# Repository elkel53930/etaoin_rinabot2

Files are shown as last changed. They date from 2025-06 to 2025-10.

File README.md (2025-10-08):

# 璃奈ちゃんbot TYPE2

このリポジトリは、同人誌「璃奈ちゃんを作ろう！TYPE2」の参考資料を公開するものです。

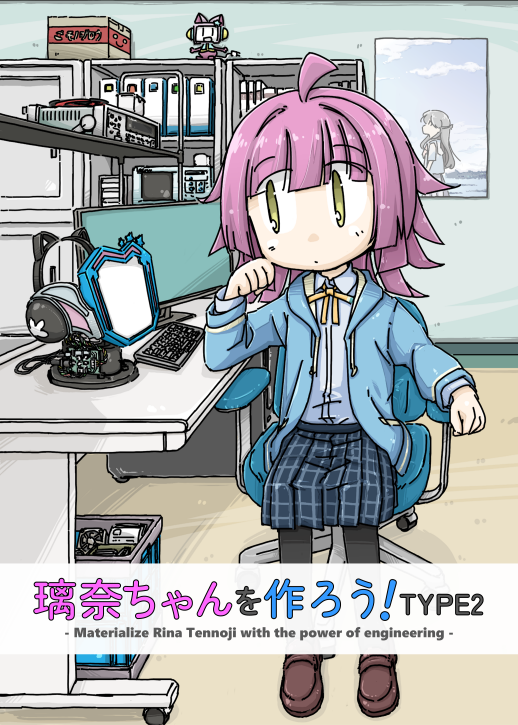
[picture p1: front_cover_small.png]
"璃奈ちゃんを作ろう！TYPE2 表紙画像"


## ディレクトリ構成

```
etaoin_rinabot2
├── app : 主にPythonスクリプト
│   ├── board : 璃奈ちゃんboard
│   ├── drive : 璃奈ちゃんdrive
│   ├── etc : その他スクリプト
│   ├── frame : 璃奈ちゃんframe
│   ├── rinabot : 高レベルスクリプトやシナリオ実行スクリプト
│   ├── scenario : サンプルシナリオファイル
│   ├── slide : スライドショー機能
│   └── speech : 璃奈ちゃんspeech
├── elec : 各プリント基板のKiCadデータ
│   ├── board : 璃奈ちゃんboard制御基板
│   ├── hub : ハブ基板
│   ├── led_a : LEDのモジュール
│   └── motor_driver : 璃奈ちゃんdrive制御基板
└── fsw : ファームウェア
　   ├── board : 璃奈ちゃんboard
　   └── drive : 璃奈ちゃんdrive
```

## 3DCADデータ

3DCADデータは以下のURLで公開しています。
Google Chromeでは表示できないことがあるようです。
Microsoft Edgeで閲覧可能であることを確認しています。

https://a360.co/4q07Nhn

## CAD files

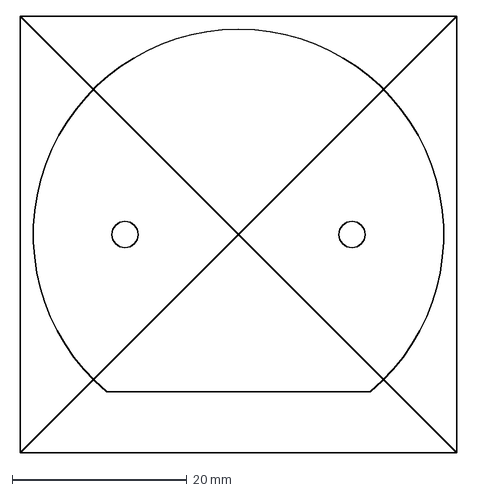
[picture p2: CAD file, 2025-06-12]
elec/motor_driver/outline.dxf
50.9 x 50.0 mm

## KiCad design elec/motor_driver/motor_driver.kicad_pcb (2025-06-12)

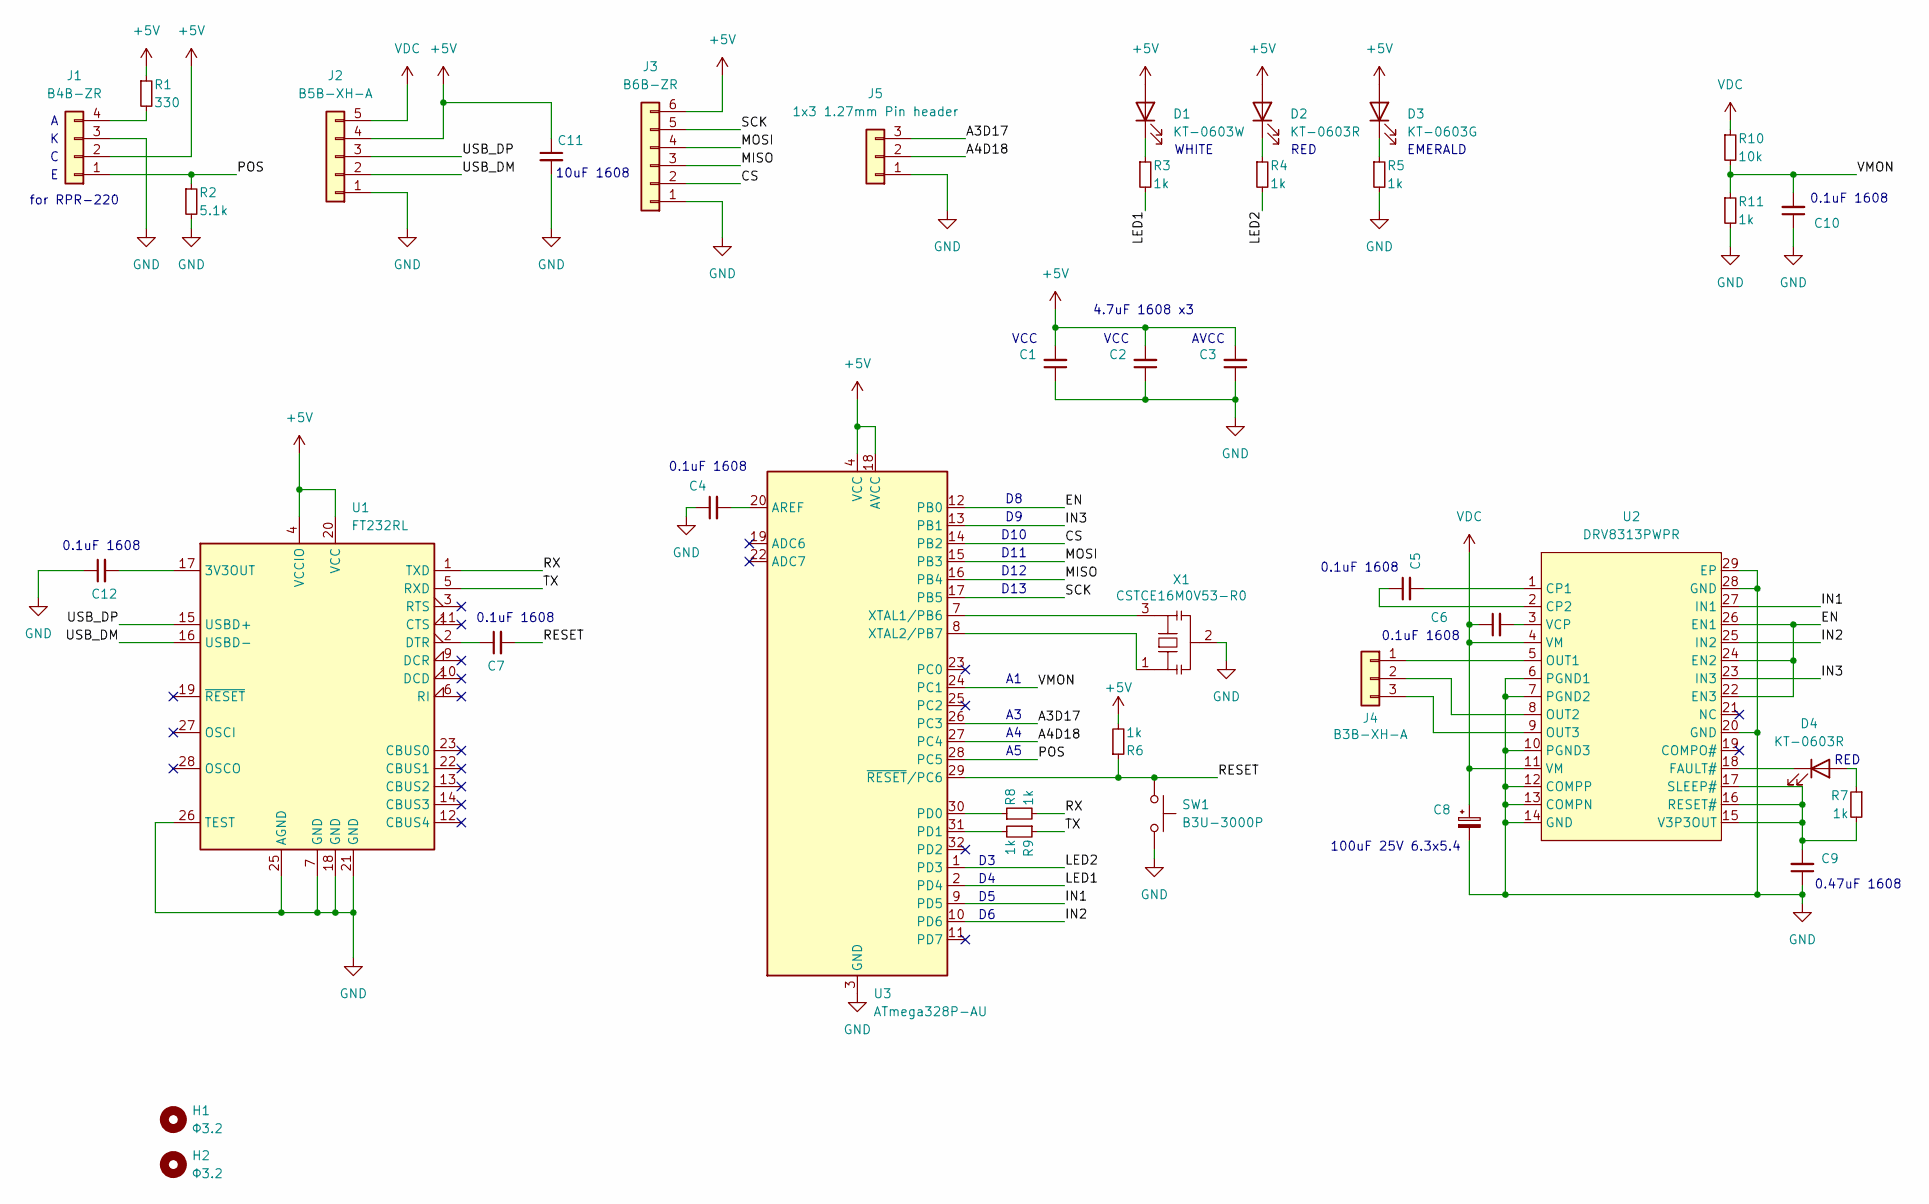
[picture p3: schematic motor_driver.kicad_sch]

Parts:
C1, C2, C3: CL10A475KO8NNNC; C_0603_1608Metric
C4, C5, C6, C7, C10, C12: CC0603KRX7R9BB104; C_0603_1608Metric
C8: RST100UF25V004; CP_Elec_6.3x5.4
C9: CL10B474KA8NNNC; C_0603_1608Metric
C11: CL10A106KP8NNNC; C_0603_1608Metric
D1: KT-0603W; LED_0603_1608Metric
D2, D4: KT-0603R; LED_0603_1608Metric
D3: KT-0603G; LED_0603_1608Metric
H1, H2: Φ3.2; MountingHole_3.2mm_M3
J1: B4B-ZR; JST_ZH_B4B-ZR_1x04_P1.50mm_Vertical
J2: B5B-XH-A; JST_XH_B5B-XH-A_1x05_P2.50mm_Vertical
J3: B6B-ZR; JST_ZH_B6B-ZR_1x06_P1.50mm_Vertical
J4: B3B-XH-A; JST_XH_B3B-XH-A_1x03_P2.50mm_Vertical
J5: 1x3 1.27mm Pin header; PinHeader_1x03_P1.27mm_Vertical
R1: 330; R_0603_1608Metric
R2: 5.1k; R_0603_1608Metric
R3, R4, R5, R6, R7, R8, R9, R11: 1k; R_0603_1608Metric
R10: 10k; R_0603_1608Metric
SW1: B3U-3000P; SW_SPST_B3U-3000P-B
U1: FT232RL; SSOP-28_5.3x10.2mm_P0.65mm
U2: DRV8313PWPR; HTSSOP-28-1EP_4.4x9.7mm_P0.65mm_EP2.75x6.2mm_ThermalVias
U3: ATmega328P-AU; TQFP-32_7x7mm_P0.8mm
X1: CSTCE16M0V53-R0; CSTCE

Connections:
+5V: C1.2, C2.2, C3.2, C11.1, D1.2 (A), D2.2 (A), D3.2 (A), J1.2, J2.4, J3.6, R1.1, R6.2, U1.4 (VCCIO), U1.20 (VCC), U3.4 (VCC), U3.6 (VCC), U3.18 (AVCC)
/A3D17: J5.3, U3.26 (PC3)
/A4D18: J5.2, U3.27 (PC4)
/CS: J3.2, U3.14 (PB2)
/EN: U2.22 (EN3), U2.24 (EN2), U2.26 (EN1), U3.12 (PB0)
/IN1: U2.27 (IN1), U3.9 (PD5)
/IN2: U2.25 (IN2), U3.10 (PD6)
/IN3: U2.23 (IN3), U3.13 (PB1)
/LED1: R3.2, U3.2 (PD4)
/LED2: R4.2, U3.1 (PD3)
/MISO: J3.3, U3.16 (PB4)
/MOSI: J3.4, U3.15 (PB3)
/POS: J1.1, R2.1, U3.28 (PC5)
/RESET: C7.2, R6.1, SW1.1, U3.29 (~RESET/PC6)
/RX: R8.2, U1.1 (TXD)
/SCK: J3.5, U3.17 (PB5)
/TX: R9.1, U1.5 (RXD)
/USB_DM: J2.2, U1.16 (USBD-)
/USB_DP: J2.3, U1.15 (USBD+)
/VMON: C10.2, R10.2, R11.1, U3.24 (PC1)
GND: C1.1, C2.1, C3.1, C4.1, C8.2, C9.1, C10.1, C11.2, C12.1, J1.3, J2.1, J3.1, J5.1, R2.2, R5.2, R11.2, SW1.2, U1.7 (GND), U1.18 (GND), U1.21 (GND), U1.25 (AGND), U1.26 (TEST), U2.6 (PGND1), U2.7 (PGND2), U2.10 (PGND3), U2.12 (COMPP), U2.13 (COMPN), U2.14 (GND), U2.20 (GND), U2.28 (GND), U2.29 (EP), U3.3 (GND), U3.5 (GND), U3.21 (GND), X1.2
unnamed: D1.1 (K), R3.1
unnamed: D2.1 (K), R4.1
unnamed: D3.1 (K), R5.1
unnamed: D4.2 (A), R7.1
unnamed: D4.1 (K), U2.18 (FAULT#)
unnamed: J1.4, R1.2
unnamed: J4.1, U2.5 (OUT1)
unnamed: J4.2, U2.8 (OUT2)
unnamed: J4.3, U2.9 (OUT3)
unnamed: C12.2, U1.17 (3V3OUT)
unnamed: C7.1, U1.2 (DTR)
unnamed: C5.2, U2.1 (CP1)
unnamed: C5.1, U2.2 (CP2)
unnamed: C9.2, R7.2, U2.15 (V3P3OUT), U2.16 (RESET#), U2.17 (SLEEP#)
unnamed: C6.2, U2.3 (VCP)
unnamed: C4.2, U3.20 (AREF)
unnamed: R8.1, U3.30 (PD0)
unnamed: R9.2, U3.31 (PD1)
unnamed: U3.7 (XTAL1/PB6), X1.3
unnamed: U3.8 (XTAL2/PB7), X1.1
VDC: C6.1, C8.1, J2.5, R10.1, U2.4 (VM), U2.11 (VM)

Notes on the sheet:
D12
VCC
RED
D10
EMERALD
0.1uF 1608
WHITE
100uF 25V 6.3x5.4
10uF 1608
AVCC
for RPR-220
0.47uF 1608
4.7uF 1608 x3
D13
D11

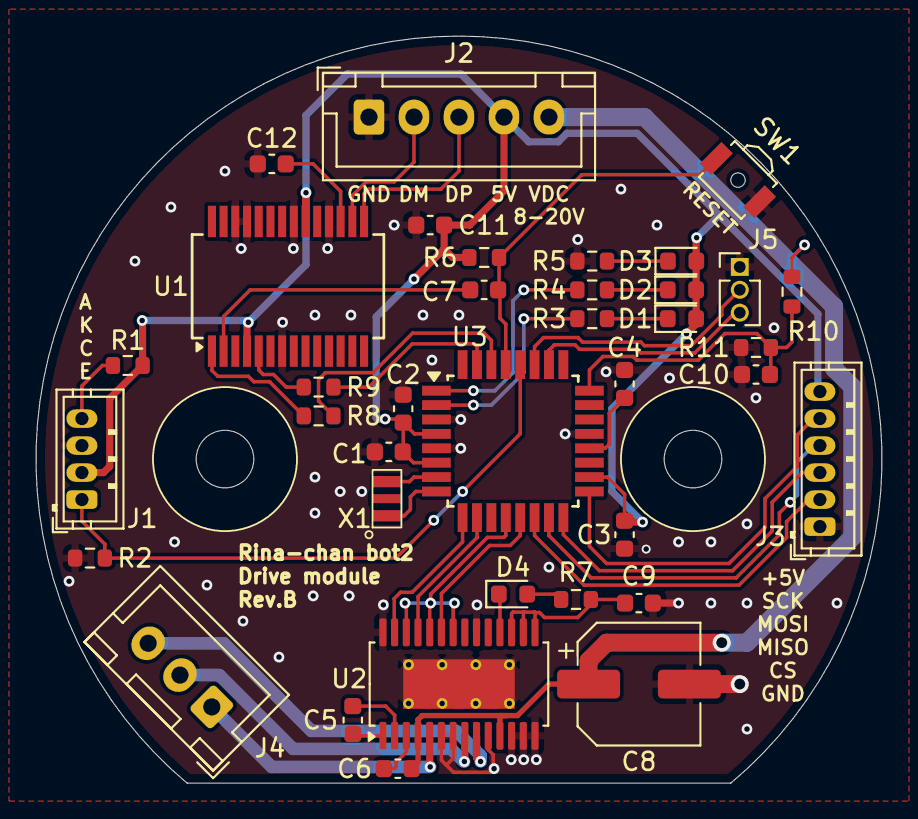
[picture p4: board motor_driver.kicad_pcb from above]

Board: 2 copper layers, 47.0 x 41.5 mm, 39 parts (0 on the bottom side), 42 nets.

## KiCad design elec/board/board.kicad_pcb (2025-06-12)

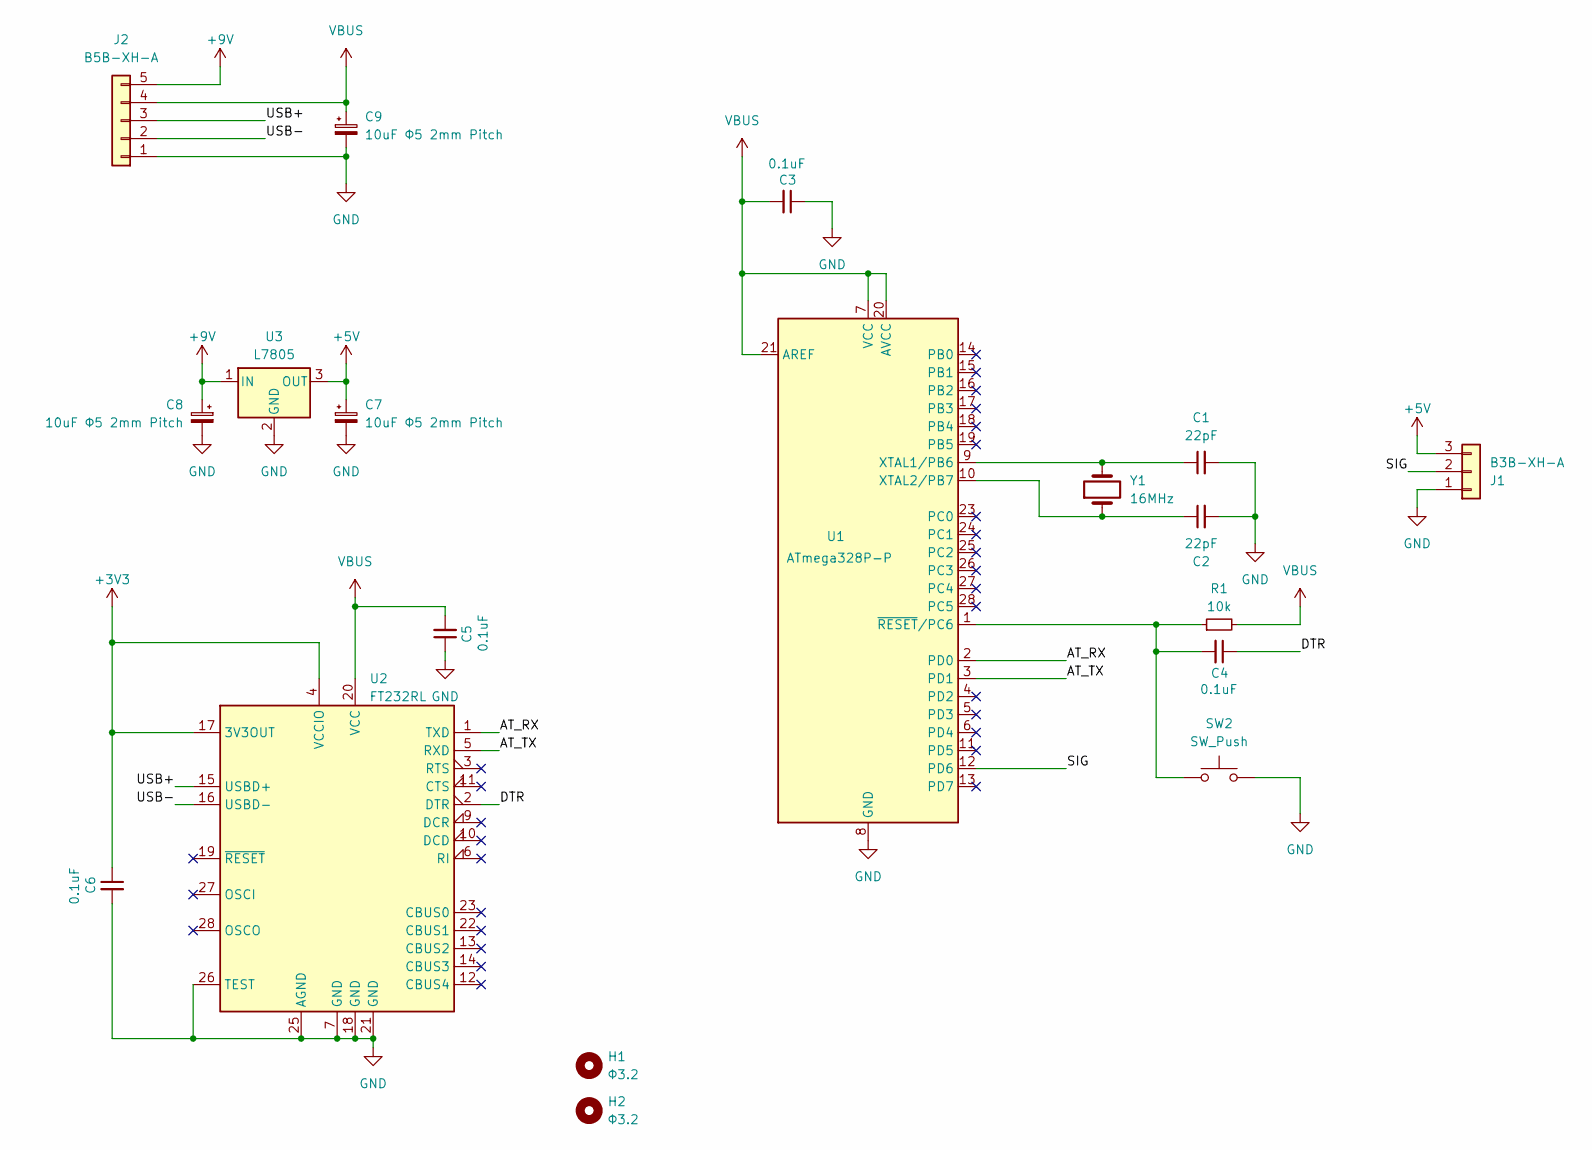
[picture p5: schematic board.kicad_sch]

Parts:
C1, C2: 22pF; C_Disc_D5.1mm_W3.2mm_P5.00mm
C3, C4, C5, C6: 0.1uF; C_Disc_D5.1mm_W3.2mm_P5.00mm
C7, C8, C9: 10uF Φ5 2mm Pitch; CP_Radial_D5.0mm_P2.00mm
H1, H2: Φ3.2; MountingHole_3.2mm_M3
J1: B3B-XH-A; JST_XH_B3B-XH-A_1x03_P2.50mm_Vertical
J2: B5B-XH-A; JST_XH_B5B-XH-A_1x05_P2.50mm_Vertical
R1: 10k; R_Axial_DIN0207_L6.3mm_D2.5mm_P7.62mm_Horizontal
SW2: SW_Push; SW_PUSH_6mm
U1: ATmega328P-P; DIP-28_W7.62mm
U2: FT232RL; SSOP-28_5.3x10.2mm_P0.65mm
U3: L7805; TO-220F-3_Vertical
Y1: 16MHz; Crystal_HC49-4H_Vertical

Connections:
+3V3: C6.1, U2.4 (VCCIO), U2.17 (3V3OUT)
+5V: C7.1, J1.3, U3.3 (OUT)
+9V: C8.1, J2.5, U3.1 (IN)
/AT_RX: U1.2 (PD0), U2.1 (TXD)
/AT_TX: U1.3 (PD1), U2.5 (RXD)
/DTR: C4.1, U2.2 (DTR)
/SIG: J1.2, U1.12 (PD6)
/USB+: J2.3, U2.15 (USBD+)
/USB-: J2.2, U2.16 (USBD-)
GND: C1.2, C2.2, C3.1, C5.1, C6.2, C7.2, C8.2, C9.2, J1.1, J2.1, SW2.2, U1.8 (GND), U1.22 (GND), U2.7 (GND), U2.18 (GND), U2.21 (GND), U2.25 (AGND), U2.26 (TEST), U3.2 (GND)
unnamed: C1.1, U1.9 (XTAL1/PB6), Y1.2
unnamed: C2.1, U1.10 (XTAL2/PB7), Y1.1
unnamed: C4.2, R1.1, SW2.1, U1.1 (~RESET/PC6)
VBUS: C3.2, C5.2, C9.1, J2.4, R1.2, U1.7 (VCC), U1.20 (AVCC), U1.21 (AREF), U2.20 (VCC)

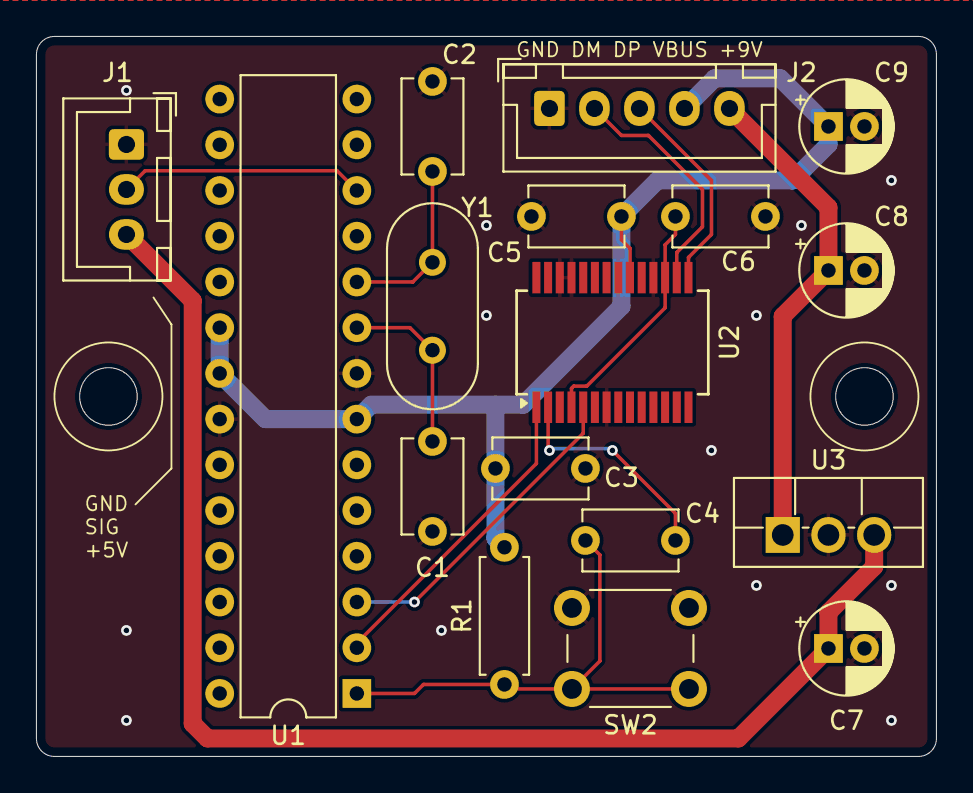
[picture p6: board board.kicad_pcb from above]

Board: 2 copper layers, 50.0 x 40.0 mm, 19 parts (0 on the bottom side), 14 nets.

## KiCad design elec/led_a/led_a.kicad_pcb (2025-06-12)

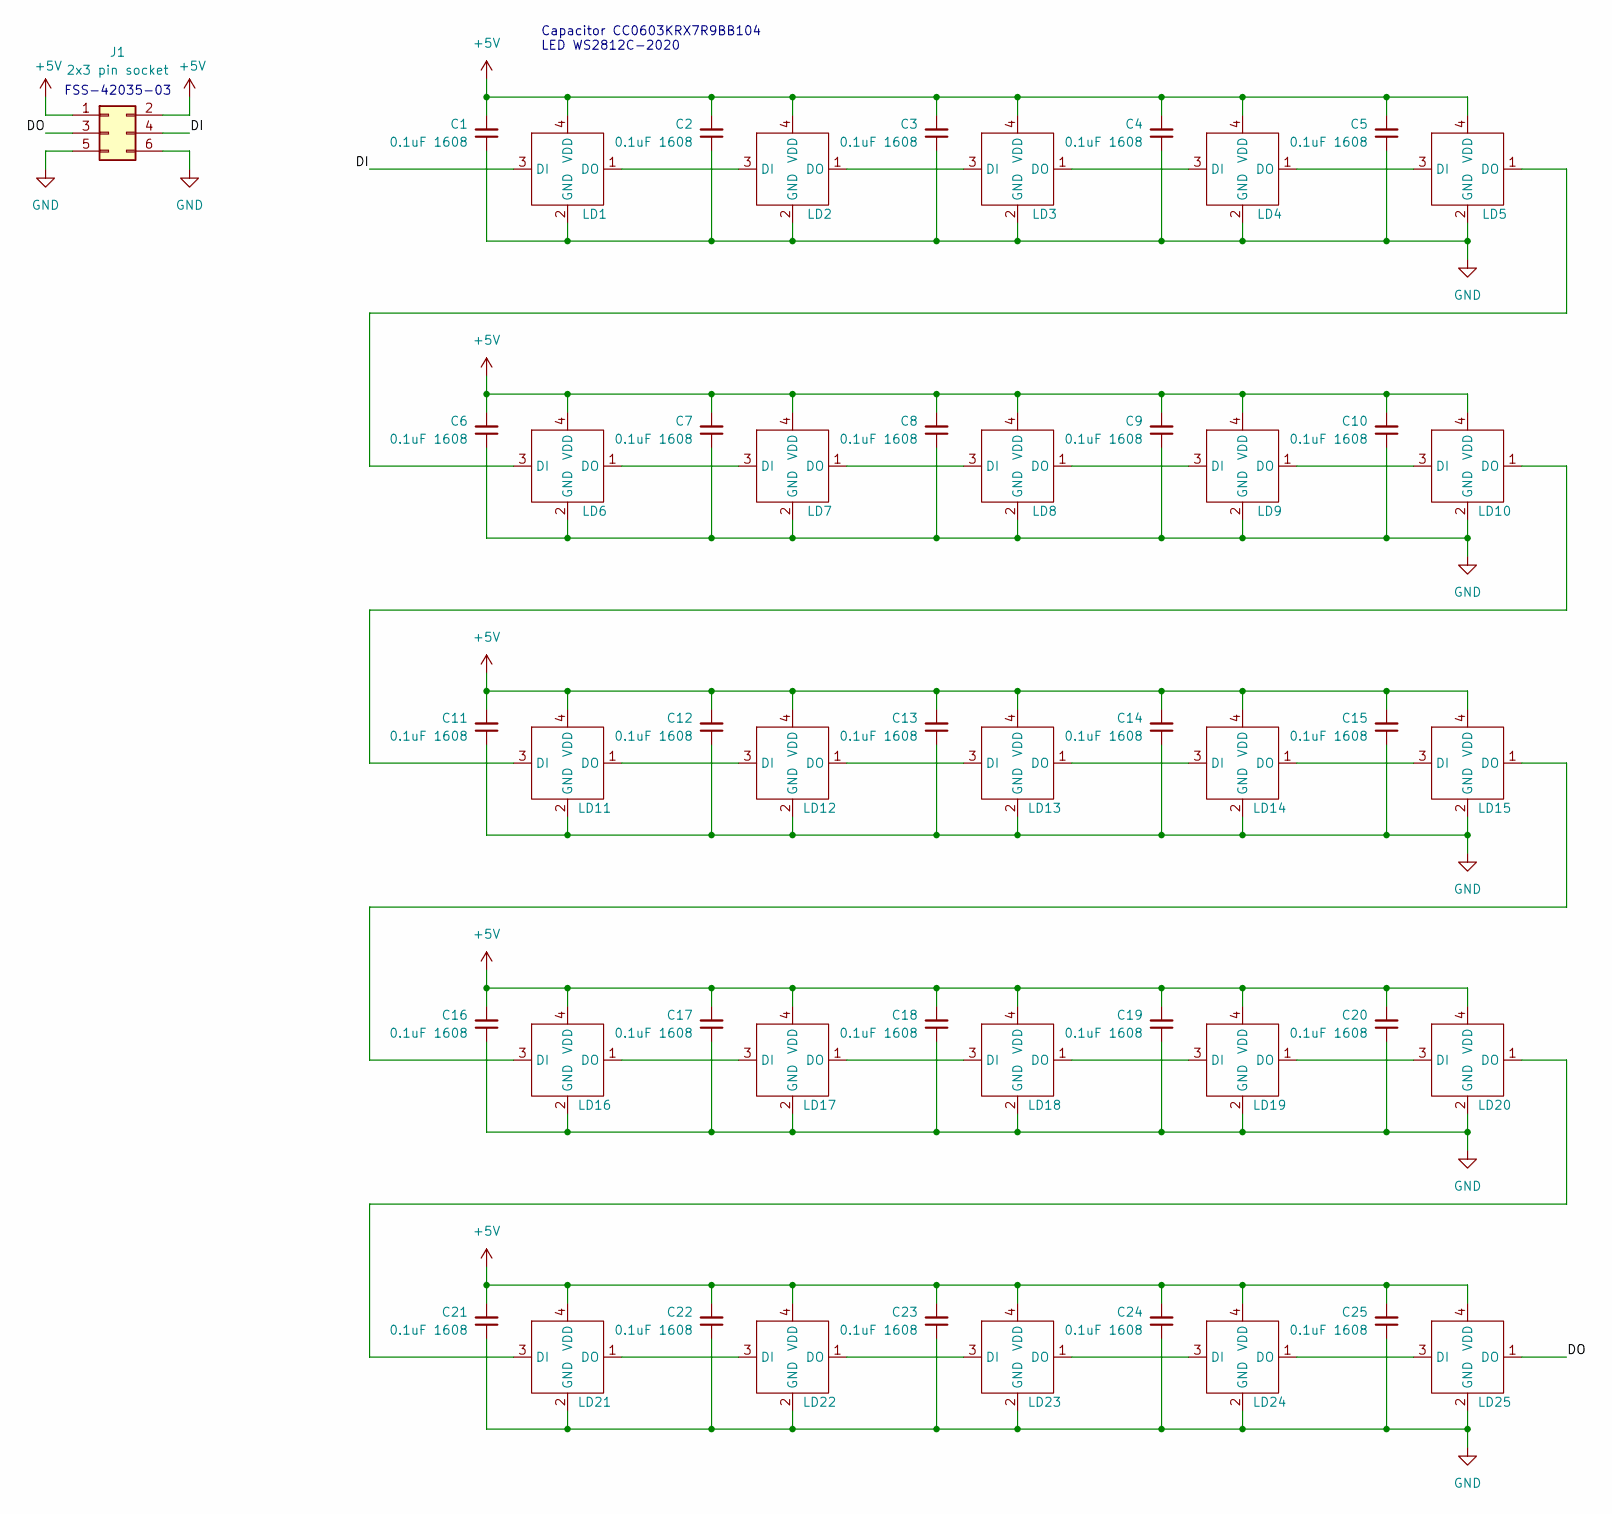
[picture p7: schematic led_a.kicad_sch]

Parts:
C1, C2, C3, C4, C5, C6, C7, C8, C9, C10, C11, C12, C13, C14, C15, C16, C17, C18, C19, C20, C21, C22, C23, C24, C25: 0.1uF 1608; C_0603_1608Metric
J1: 2x3 pin socket; PinHeader_2x03_P2.54mm_Vertical
LD1, LD2, LD3, LD4, LD5, LD6, LD7, LD8, LD9, LD10, LD11, LD12, LD13, LD14, LD15, LD16, LD17, LD18, LD19, LD20, LD21, LD22, LD23, LD24, LD25: LED_WS2812B-2020_PLCC4_2.0x2.0mm

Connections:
+5V: C1.2, C2.2, C3.2, C4.2, C5.2, C6.2, C7.2, C8.2, C9.2, C10.2, C11.2, C12.2, C13.2, C14.2, C15.2, C16.2, C17.2, C18.2, C19.2, C20.2, C21.2, C22.2, C23.2, C24.2, C25.2, J1.1, J1.2, LD1.4 (VDD), LD2.4 (VDD), LD3.4 (VDD), LD4.4 (VDD), LD5.4 (VDD), LD6.4 (VDD), LD7.4 (VDD), LD8.4 (VDD), LD9.4 (VDD), LD10.4 (VDD), LD11.4 (VDD), LD12.4 (VDD), LD13.4 (VDD), LD14.4 (VDD), LD15.4 (VDD), LD16.4 (VDD), LD17.4 (VDD), LD18.4 (VDD), LD19.4 (VDD), LD20.4 (VDD), LD21.4 (VDD), LD22.4 (VDD), LD23.4 (VDD), LD24.4 (VDD), LD25.4 (VDD)
/DI: J1.4, LD1.3 (DI)
/DO: J1.3, LD25.1 (DO)
GND: C1.1, C2.1, C3.1, C4.1, C5.1, C6.1, C7.1, C8.1, C9.1, C10.1, C11.1, C12.1, C13.1, C14.1, C15.1, C16.1, C17.1, C18.1, C19.1, C20.1, C21.1, C22.1, C23.1, C24.1, C25.1, J1.5, J1.6, LD1.2 (GND), LD2.2 (GND), LD3.2 (GND), LD4.2 (GND), LD5.2 (GND), LD6.2 (GND), LD7.2 (GND), LD8.2 (GND), LD9.2 (GND), LD10.2 (GND), LD11.2 (GND), LD12.2 (GND), LD13.2 (GND), LD14.2 (GND), LD15.2 (GND), LD16.2 (GND), LD17.2 (GND), LD18.2 (GND), LD19.2 (GND), LD20.2 (GND), LD21.2 (GND), LD22.2 (GND), LD23.2 (GND), LD24.2 (GND), LD25.2 (GND)
unnamed: LD1.1 (DO), LD2.3 (DI)
unnamed: LD2.1 (DO), LD3.3 (DI)
unnamed: LD3.1 (DO), LD4.3 (DI)
unnamed: LD4.1 (DO), LD5.3 (DI)
unnamed: LD5.1 (DO), LD6.3 (DI)
unnamed: LD6.1 (DO), LD7.3 (DI)
unnamed: LD7.1 (DO), LD8.3 (DI)
unnamed: LD8.1 (DO), LD9.3 (DI)
unnamed: LD9.1 (DO), LD10.3 (DI)
unnamed: LD10.1 (DO), LD11.3 (DI)
unnamed: LD11.1 (DO), LD12.3 (DI)
unnamed: LD12.1 (DO), LD13.3 (DI)
unnamed: LD13.1 (DO), LD14.3 (DI)
unnamed: LD14.1 (DO), LD15.3 (DI)
unnamed: LD15.1 (DO), LD16.3 (DI)
unnamed: LD16.1 (DO), LD17.3 (DI)
unnamed: LD17.1 (DO), LD18.3 (DI)
unnamed: LD18.1 (DO), LD19.3 (DI)
unnamed: LD19.1 (DO), LD20.3 (DI)
unnamed: LD20.1 (DO), LD21.3 (DI)
unnamed: LD21.1 (DO), LD22.3 (DI)
unnamed: LD22.1 (DO), LD23.3 (DI)
unnamed: LD23.1 (DO), LD24.3 (DI)
unnamed: LD24.1 (DO), LD25.3 (DI)

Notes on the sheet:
Capacitor CC0603KRX7R9BB104 LED WS2812C-2020
FSS-42035-03

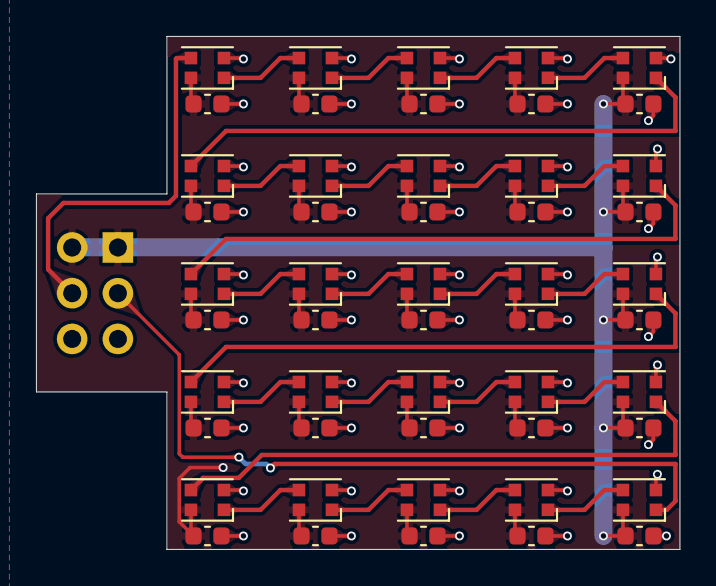
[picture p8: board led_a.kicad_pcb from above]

Board: 2 copper layers, 35.8 x 28.5 mm, 51 parts (1 on the bottom side), 28 nets.

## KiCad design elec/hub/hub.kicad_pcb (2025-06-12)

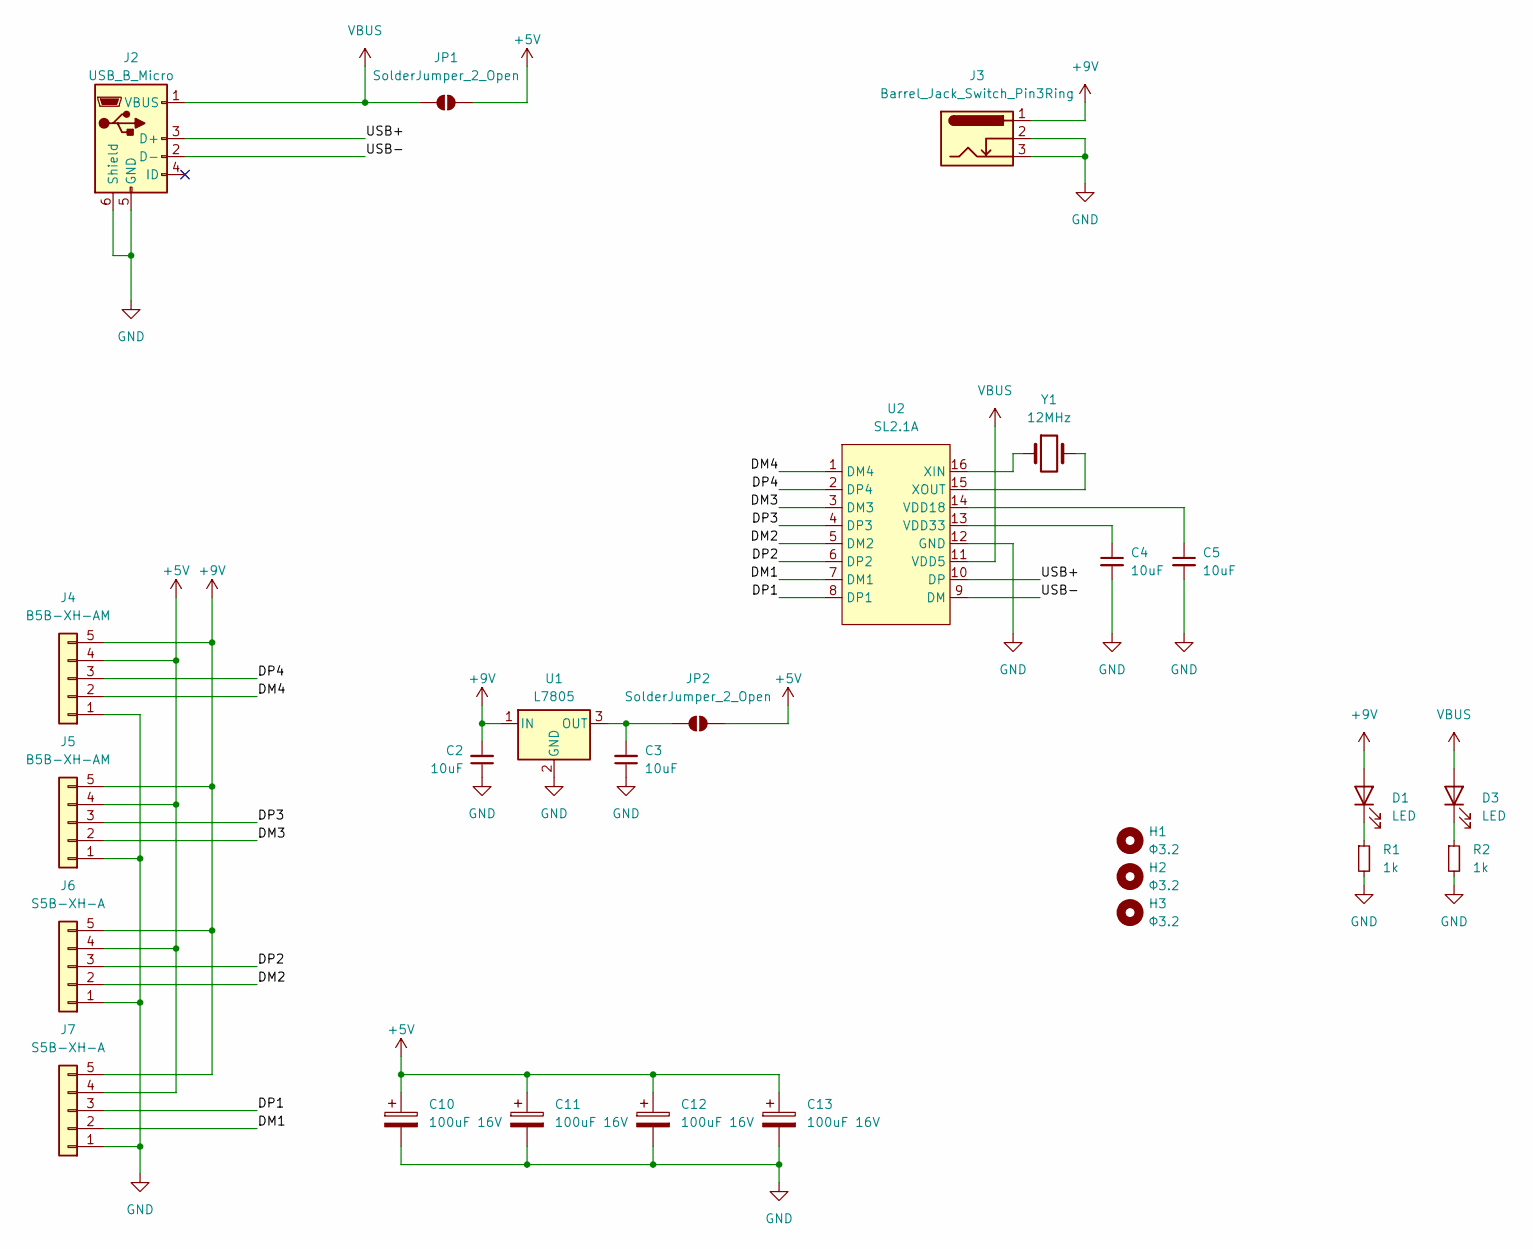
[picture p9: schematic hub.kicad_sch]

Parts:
C2, C3, C4, C5: 10uF; C_0805_2012Metric
C10, C11, C12, C13: 100uF 16V; CP_Elec_6.3x5.4
D1, D3: LED; LED_0603_1608Metric
H1, H2, H3: Φ3.2; MountingHole_3.2mm_M3
J2: USB_B_Micro; USB_Micro-B_Molex-105017-0001
J3: Barrel_Jack_Switch_Pin3Ring; PJ-002A
J4, J5: B5B-XH-AM; JST_XH_B5B-XH-AM_1x05_P2.50mm_Vertical
J6, J7: S5B-XH-A; JST_XH_S5B-XH-A_1x05_P2.50mm_Horizontal
JP1, JP2: SolderJumper_2_Open; SolderJumper-2_P1.3mm_Open_Pad1.0x1.5mm
R1, R2: 1k; R_0603_1608Metric
U1: L7805; TO-252-2
U2: SL2.1A; SOP-16_3.9x9.9mm_P1.27mm
Y1: 12MHz; Crystal_HC49-4H_Vertical

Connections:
+5V: C10.1, C11.1, C12.1, C13.1, J4.4, J5.4, J6.4, J7.4, JP1.1 (A), JP2.1 (A)
+9V: C2.2, D1.2 (A), J3.1, J4.5, J5.5, J6.5, J7.5, U1.1 (IN)
/DM1: J7.2, U2.7 (DM1)
/DM2: J6.2, U2.5 (DM2)
/DM3: J5.2, U2.3 (DM3)
/DM4: J4.2, U2.1 (DM4)
/DP1: J7.3, U2.8 (DP1)
/DP2: J6.3, U2.6 (DP2)
/DP3: J5.3, U2.4 (DP3)
/DP4: J4.3, U2.2 (DP4)
/USB+: J2.3 (D+), U2.10 (DP); also elsewhere on the board
/USB-: J2.2 (D-), U2.9 (DM); also elsewhere on the board
GND: C2.1, C3.1, C4.2, C5.2, C10.2, C11.2, C12.2, C13.2, J2.5 (GND), J2.6 (Shield), J3.2, J3.3, J4.1, J5.1, J6.1, J7.1, R1.2, R2.2, U1.2 (GND), U2.12 (GND); also elsewhere on the board
unnamed: D1.1 (K), R1.1
unnamed: D3.1 (K), R2.1
unnamed: C3.2, JP2.2 (B), U1.3 (OUT)
unnamed: C5.1, U2.14 (VDD18)
unnamed: C4.1, U2.13 (VDD33)
unnamed: U2.16 (XIN), Y1.1
unnamed: U2.15 (XOUT), Y1.2
VBUS: D3.2 (A), J2.1 (VBUS), JP1.2 (B), U2.11 (VDD5); also elsewhere on the board

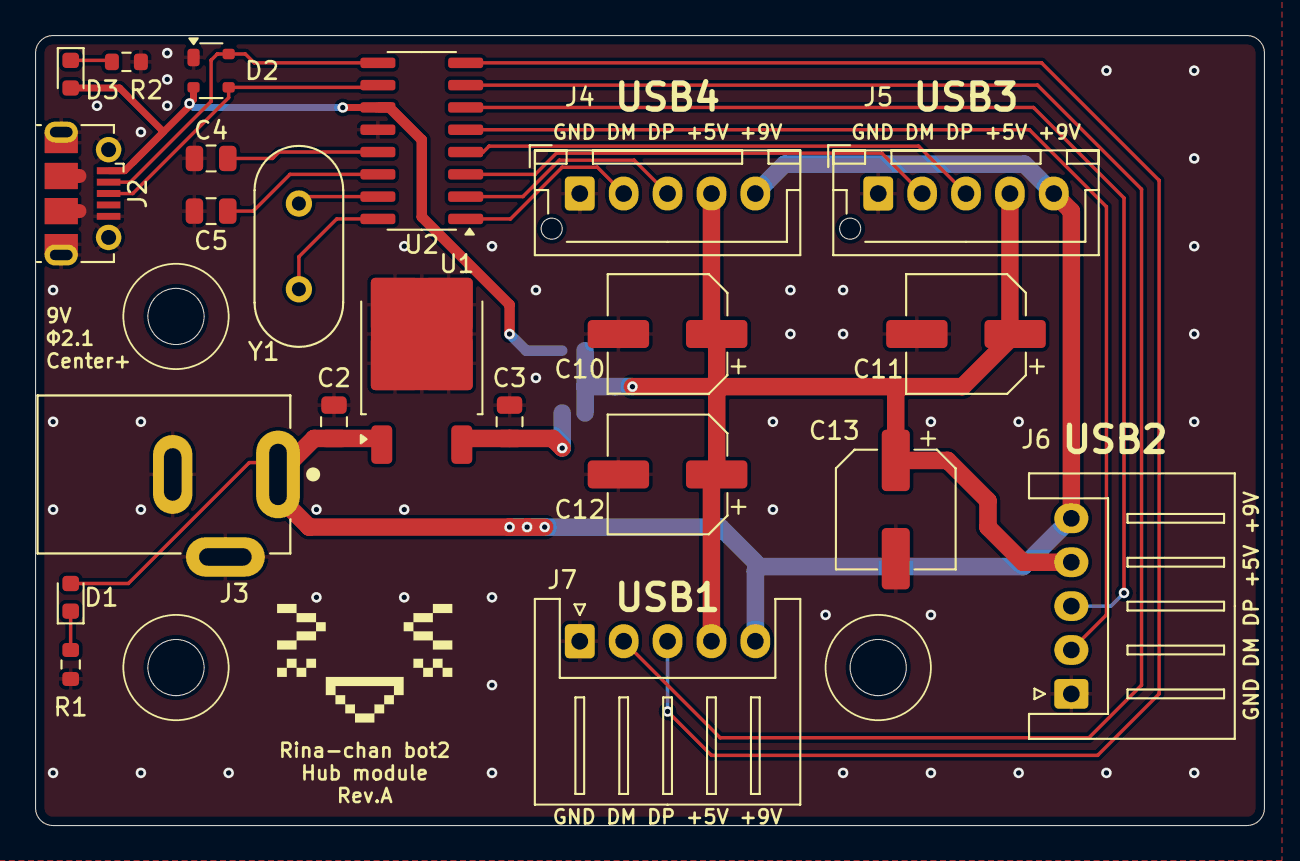
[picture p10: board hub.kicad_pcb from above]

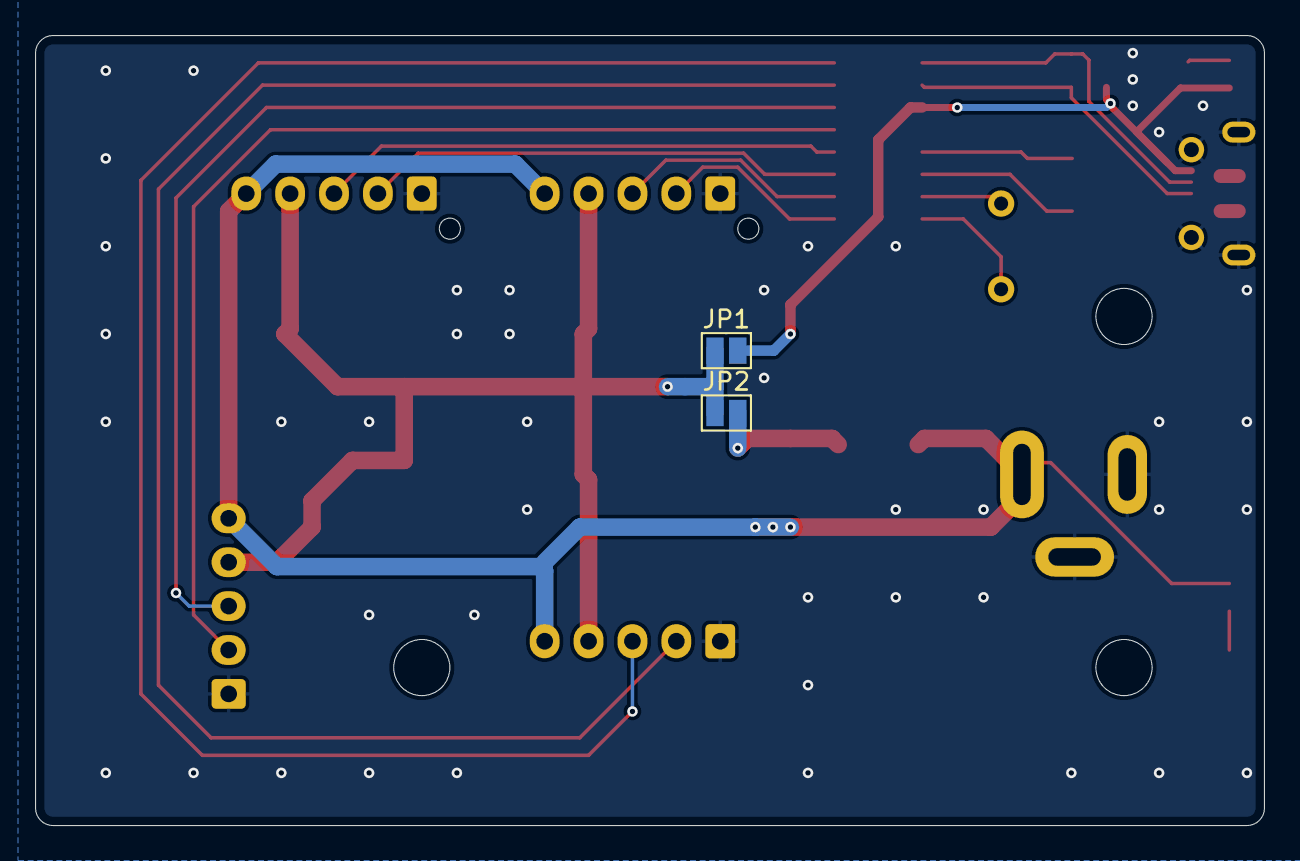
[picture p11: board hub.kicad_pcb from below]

Board: 2 copper layers, 70.0 x 45.0 mm, 27 parts (2 on the bottom side), 21 nets.

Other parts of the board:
D2: SP0503BAHT; SOT-143

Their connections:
/USB+: D2.3 (K); also elsewhere on the board
/USB-: D2.4 (K); also elsewhere on the board
GND: D2.1 (A); also elsewhere on the board
VBUS: D2.2 (K); also elsewhere on the board

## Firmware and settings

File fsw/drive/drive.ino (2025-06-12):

#include <SimpleFOC.h>
#include "SimpleFOCDrivers.h"
#include "encoders/as5048a/MagneticSensorAS5048A.h"

// magnetic sensor instance - SPI
MagneticSensorAS5048A sensor(10);

// BLDC motor & driver instance
BLDCMotor motor = BLDCMotor(11);

BLDCDriver3PWM driver = BLDCDriver3PWM(9, 5, 6, 8);
const int absSensorPin = A5;
const int vmonPin = A1;

const int INPUT_GEAR = 12;
const int OUTPUT_GEAR = 93;
const double GEAR_RATIO = (double)OUTPUT_GEAR / (double)INPUT_GEAR;

#define J3

// 以下のパラメータは個体依存
// J1
#ifdef J1
const int absThreshold = 100;
#define SENSOR_DIRECTION Direction::CW
#define ZERO_ELECTRIC_ANGLE (2.6852)
#endif

// J2
#ifdef J2
const int absThreshold = 100;
#define SENSOR_DIRECTION Direction::CW
#define ZERO_ELECTRIC_ANGLE (5.3076)
#endif

// J3
#ifdef J3
const int absThreshold = 100;
#define SENSOR_DIRECTION Direction::CW
#define ZERO_ELECTRIC_ANGLE (1.5357)
#endif

struct CTX {
  bool is_initialized;
  float target_angle;
} ctx;

unsigned char read() {
  while (Serial.available() == 0) {
    // do nothing
  }
  return Serial.read();
}

unsigned short read2() {
  unsigned char upper = read();
  unsigned char lower = read();
  return (unsigned short)upper * 256 + (unsigned short)lower;
}

void (*resetFunc)(void) = 0;

void init_actuator(float p, float i, float d, float tf) {
  if (ctx.is_initialized) {
    return;
  }
  // init sensor
  sensor.init();
  motor.linkSensor(&sensor);
  // init driver
  float motor_voltage = getMotorVoltage();
  driver.voltage_power_supply = motor_voltage;
  driver.voltage_limit = motor_voltage;
  driver.init();
  motor.linkDriver(&driver);

  // init motor
  motor.controller = MotionControlType::angle;
  motor.voltage_limit = motor_voltage;
  motor.current_limit = 0.5;
  motor.velocity_limit = 20;

  motor.P_angle.P = p;
  motor.P_angle.I = i;
  motor.P_angle.D = d;

  motor.PID_velocity.P = 0.2f;
  motor.PID_velocity.I = 11.0f;

  motor.LPF_velocity.Tf = tf;

  motor.sensor_direction = SENSOR_DIRECTION;
  motor.zero_electric_angle = ZERO_ELECTRIC_ANGLE;

  motor.init();
  motor.initFOC();

  ctx.is_initialized = true;
}

void disable_actuator() {
  motor.disable();
  ctx.is_initialized = false;
}

double getOutputShaftAngle() {
  return motor.shaftAngle() / GEAR_RATIO;
}

double getInputShaftAngle() {
  return sensor.getSensorAngle();
}

float getMotorVoltage() {
  int adc_value = analogRead(vmonPin);
  float measured_voltage = ((float)adc_value / 1023.0) * 5.0;
  return measured_voltage * 11.0;
}

int getAbsSensorValue() {
  return analogRead(absSensorPin);
}

double toRad(unsigned int digit) {
  return (double)((int)digit - 2000) / 1000.0;
}

unsigned int toDigit(double rad) {
  return (unsigned int)(rad * 1000.0) + 2000;
}

// Serial.write()で2byteのデータ(unsigned short)を送信する
void write(unsigned short data) {
  Serial.write((unsigned char)(data >> 8));
  Serial.write((unsigned char)(data & 0xff));
}

void process_init_command() {
  float p = ((float)read2()) / 100.0;
  float i = ((float)read2()) / 100.0;
  float d = ((float)read2()) / 100.0;
  float tf = ((float)read2()) / 10000.0;

  init_actuator((float)p, (float)i, (float)d, tf);
  ctx.target_angle = motor.shaftAngle();
}

void process_command(unsigned char cmd) {
  int raw_digit;
  float diff;
  switch (cmd) {
    case 0x80:  // init
      process_init_command();
      break;

    case 0x81:  // disable
      disable_actuator();
      break;

    case 0x89:  // reset
      resetFunc();
      break;

    case 0x91:  // Set target position
      // 出力軸の角度[rad]*1000 + 2000の値を受け取る
      // e.g.
      //  30度の場合 : 30度 = 0.5235987755982988rad -> 2523
      //  -5度の場合 : -5度 = -0.08726646259971647rad -> 1912
      ctx.target_angle = toRad(read2()) * GEAR_RATIO;
      // 出力軸の角度を送信
      write(toDigit(getOutputShaftAngle()));
      // 入力軸の角度を送信
      write(toDigit(getInputShaftAngle()));
      // 絶対センサの値を送信
      write(getAbsSensorValue());

      break;
  
    case 0x94:  // Get angle
      // 出力軸の角度を送信
      write(toDigit(getOutputShaftAngle()));
      // 入力軸の角度を送信
      write(toDigit(getInputShaftAngle()));
      // 絶対センサの値を送信
      write(getAbsSensorValue());
      break;
  }
}

void setup() {
  Serial.begin(115200);

  ctx.is_initialized = false;
  ctx.target_angle = 0.0;
}

void loop() {
  if (Serial.available()) {
    unsigned char data = Serial.read();
    if (data & 0x80) {
      // if head bit is 1, it is a command
      process_command(data);
    }
  }

  if (ctx.is_initialized) {
    // Motion control function
    motor.move(ctx.target_angle);
    // main FOC algorithm function
    motor.loopFOC();
  }
}

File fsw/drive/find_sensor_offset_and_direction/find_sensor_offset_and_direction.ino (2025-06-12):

/**
 * Simple example intended to help users find the zero offset and natural direction of the sensor. 
 * 
 * These values can further be used to avoid motor and sensor alignment procedure. 
 * To use these values add them to the code:");
 *    motor.sensor_direction=Direction::CW; // or Direction::CCW
 *    motor.zero_electric_angle=1.2345;     // use the real value!
 * 
 * This will only work for abosolute value sensors - magnetic sensors. 
 * Bypassing the alignment procedure is not possible for the encoders and for the current implementation of the Hall sensors. 
 * library version 1.4.2.
 * 
 */
#include <SimpleFOC.h>
#include "SimpleFOCDrivers.h"
#include "encoders/as5048a/MagneticSensorAS5048A.h"

// magnetic sensor instance - SPI
//MagneticSensorSPI sensor = MagneticSensorSPI(10, 14, 0x3FFF);
// magnetic sensor instance - I2C
//MagneticSensorI2C sensor = MagneticSensorI2C(0x36, 12, 0X0C, 4);
// magnetic sensor instance - analog output
MagneticSensorAS5048A sensor(10);

// BLDC motor instance
const int VOLTAGE = 9;
BLDCMotor motor = BLDCMotor(11);
BLDCDriver3PWM driver = BLDCDriver3PWM(9, 5, 6, 8);
// Stepper motor instance
//StepperMotor motor = StepperMotor(50);
//StepperDriver4PWM driver = StepperDriver4PWM(9, 5, 10, 6,  8);

void setup() {

  // use monitoring with serial 
  Serial.begin(115200);
  // enable more verbose output for debugging
  // comment out if not needed
  SimpleFOCDebug::enable(&Serial);
#if 0
  // power supply voltage
  driver.voltage_power_supply = 9;
  driver.init();
  motor.linkDriver(&driver);

  // initialise magnetic sensor hardware
  sensor.init();
  // link the motor to the sensor
  motor.linkSensor(&sensor);

  // aligning voltage 
  motor.voltage_sensor_align = 9;
  
  // set motion control loop to be used
  motor.controller = MotionControlType::angle;

  // force direction search - because default is CW
  motor.sensor_direction = Direction::UNKNOWN;

#endif


  // init sensor
  sensor.init();
  motor.linkSensor(&sensor);
  // init driver
  driver.voltage_power_supply = VOLTAGE;
  driver.voltage_limit = VOLTAGE;
  driver.init();
  motor.linkDriver(&driver);

  // init motor
  motor.controller = MotionControlType::angle;
  motor.voltage_limit = VOLTAGE;
  motor.current_limit = 1.0;
  motor.velocity_limit = 8;

  motor.LPF_velocity.Tf = 0.01f;
  // initialize motor
  motor.init();
  // align sensor and start FOC
  motor.initFOC();

  
  Serial.println("Sensor zero offset is:");
  Serial.println(motor.zero_electric_angle, 4);
  Serial.println("Sensor natural direction is: ");
  Serial.println(motor.sensor_direction == Direction::CW ? "Direction::CW" : "Direction::CCW");

  Serial.println("To use these values add them to the code:");
  Serial.print("   motor.sensor_direction=");
  Serial.print(motor.sensor_direction == Direction::CW ? "Direction::CW" : "Direction::CCW");
  Serial.println(";");
  Serial.print("   motor.zero_electric_angle=");
  Serial.print(motor.zero_electric_angle, 4);
  Serial.println(";");

  _delay(1000);
  Serial.println("If motor is not moving the alignment procedure was not successfull!!");
}


void loop() {
    
  // main FOC algorithm function
  motor.loopFOC();

  // Motion control function
  motor.move(2);
}

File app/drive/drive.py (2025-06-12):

import serial
from time import sleep

class Drive:
    def __init__(self, port='/dev/ttyACM0'):
        # シリアル通信を初期化（ポートとボーレート指定）
        self.ser = serial.Serial(port, 115200, timeout=1)
        
        self.ser.reset_input_buffer()   # 受信バッファをクリア
        self.ser.reset_output_buffer()  # 送信バッファをクリア

        # センサやアクチュエータの状態変数
        self.input_shaft_angle = 0       # 入力側シャフトの角度
        self.output_shaft_angle = 0      # 出力側シャフトの角度
        self.abs_sensor_value = 0        # 絶対値センサの値
        self.offset = 0                  # ゼロ点補正用のオフセット

    def __del__(self):
        # インスタンス終了時にアクチュエータを無効化してシリアルポートを閉じる
        self.disable()
        self.ser.close()

    def _send(self, data):
        # シリアルにバイト列を送信
        self.ser.write(bytes(data))

    def _read_ushort(self):
        # 2バイト（unsigned short）をビッグエンディアンで受信して整数化
        return int.from_bytes(self.ser.read(2), 'big')

    def _to_rad(self, digit):
        # デジタル値をラジアンに変換（中心2000で1.0rad = 1000）
        return (digit - 2000) / 1000.0

    def _to_digit(self, rad):
        # ラジアン値をデジタル値に変換（中心2000で1.0rad = 1000）
        return int(rad * 1000 + 2000)

    def init_actuator(self, p=10, i=0, d=0, tf=0.01):
        # アクチュエータのPID制御パラメータを設定して初期化
        # p, i, dは100倍、tf（フィルタ時定数）は10000倍して整数に変換
        p = int(p * 100)
        i = int(i * 100)
        d = int(d * 100)
        tf = int(tf * 10000)
        self._send([0x80, p >> 8, p & 0xFF, i >> 8, i & 0xFF, d >> 8, d & 0xFF, tf >> 8, tf & 0xFF])
        print("Result", self.ser.readline())  # 応答読み取り
        self.get_position()                   # 現在位置を取得
        sleep(0.1)

        # ホーム（ゼロ）位置に出力シャフトを移動する（センサ値100を基準に）
        pos = self.output_shaft_angle
        if self.abs_sensor_value < 100:
            while self.abs_sensor_value < 100:
                self.set_position(pos)
                pos += 0.003
                sleep(0.01)
            pos -= 0.03
            self.set_position(pos)
        else:
            while self.abs_sensor_value >= 100:
                self.set_position(pos)
                pos -= 0.003
                sleep(0.01)
            pos += 0.03
            self.set_position(pos)

        # 現在位置をオフセットとして保存（以後の動作基準に）
        self.offset = self.output_shaft_angle
        sleep(0.1)

    def go_to_zero(self):
        # 出力シャフトをゼロ位置（オフセット補正後）に戻す
        if self.output_shaft_angle > 0:
            while self.output_shaft_angle > 0:
                self.set_position(self.output_shaft_angle - 0.0015)
                sleep(0.01)
        else:
            while self.output_shaft_angle < 0:
                self.set_position(self.output_shaft_angle + 0.0015)
                sleep(0.01)

    def stop_actuator(self):
        # アクチュエータを停止させるコマンドを送信
        self._send([0x81])
        self.ser.readline()  # 応答読み取り（破棄）

    def set_position(self, rad):
        # 指定されたラジアン位置にアクチュエータを動かす
        rad += self.offset  # オフセットを加算
        digit = self._to_digit(rad)  # デジタル値に変換
        if digit < 0:
            digit = 0  # 負値は0にクリップ
        upper = digit >> 8
        lower = digit & 0xFF
        self._send([0x91, upper, lower])  # 位置設定コマンド送信

        # 結果として得られた現在位置・入力角・センサ値を取得
        self.output_shaft_angle = self._to_rad(self._read_ushort()) - self.offset
        self.input_shaft_angle = self._to_rad(self._read_ushort())
        self.abs_sensor_value = self._read_ushort()

    def get_position(self):
        # 現在の位置とセンサ値を取得する
        self._send([0x94])  # 位置取得コマンド
        self.output_shaft_angle = self._to_rad(self._read_ushort()) - self.offset
        self.input_shaft_angle = self._to_rad(self._read_ushort())
        self.abs_sensor_value = self._read_ushort()

    def disable(self):
        # アクチュエータを無効化（停止）
        self._send([0x81])

    def reset(self):
        # システムをリセット（初期化）
        self._send([0x89])
